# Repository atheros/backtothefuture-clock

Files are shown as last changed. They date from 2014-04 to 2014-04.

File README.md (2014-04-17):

Back To The Future Time Circuit Clock
=====================================

About
-----

This repository contains or documents and source code related to my Back To The Future Time Circuit Clock project.

All project details are hosted on hackaday.io: http://hackaday.io/project/709-Back-To-The-Future-Time-Circuit-Clock

This project is part of Hackaday Porjects Sci-Fi contest: http://hackaday.io/page/276

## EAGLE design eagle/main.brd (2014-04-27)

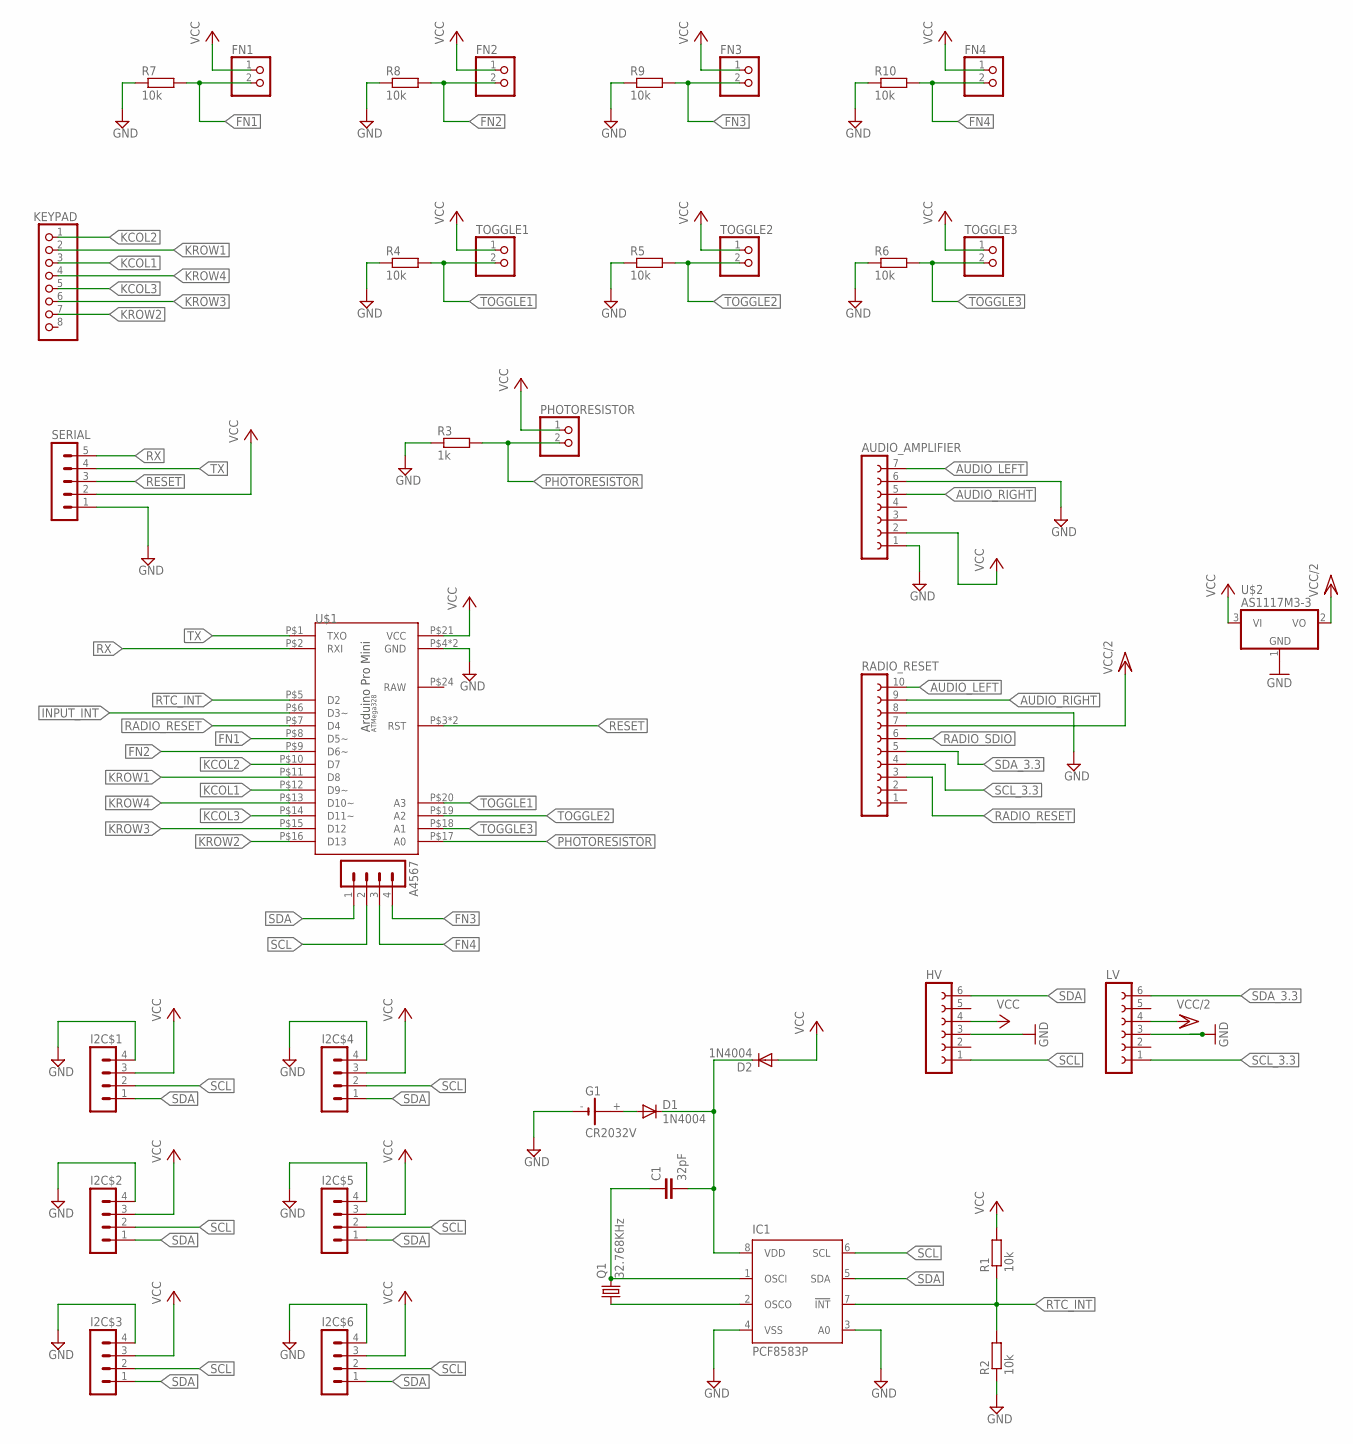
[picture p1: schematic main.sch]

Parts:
A4567: MA04-1
AUDIO_AMPLIFIER: FE07-1; FE07
C1: 32pF; C025-024X044
D1, D2: 1N4004; DO41-10
FN1, FN2, FN3, FN4: PINHD-1X2; 1X02
G1: CR2032V
HV: FE06-1; FE06
I2C$1, I2C$2, I2C$3, I2C$4, I2C$5, I2C$6: MA04-1
IC1: PCF8583P; DIL08
KEYPAD: PINHD-1X8; 1X08
LV: FE06-1; FE06
PHOTORESISTOR: PINHD-1X2; 1X02
Q1: 32.768KHz; TC26H
R1, R2, R4, R5, R6, R7, R8, R9, R10: 10k; M0805
R3: 1k; M0805
RADIO_RESET: FE10-1; FE10
SERIAL: MA05-1
TOGGLE1, TOGGLE2, TOGGLE3: PINHD-1X2; 1X02
U$1: ARDUINO-PRO-MINI-BARE; DIP24W
U$2: AS1117M3-3; SOT223

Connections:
AUDIO_LEFT: AUDIO_AMPLIFIER.7, RADIO_RESET.10
AUDIO_RIGHT: AUDIO_AMPLIFIER.5, RADIO_RESET.9
FN1: FN1.2, R7.2, U$1.P$8 (D5~)
FN2: FN2.2, R8.2, U$1.P$9 (D6~)
FN3: A4567.4, FN3.2, R9.2
FN4: A4567.3, FN4.2, R10.2
GND: AUDIO_AMPLIFIER.1, AUDIO_AMPLIFIER.6, G1.-, HV.3, I2C$1.4, I2C$2.4, I2C$3.4, I2C$4.4, I2C$5.4, I2C$6.4, IC1.3 (A0), IC1.4 (VSS), LV.3, R2.1, R3.1, R4.1, R5.1, R6.1, R7.1, R8.1, R9.1, R10.1, RADIO_RESET.8, SERIAL.1, U$1.P$4 (GND), U$1.P$23 (GND), U$2.1 (GND)
INPUT_INT: U$1.P$6 (D3~)
KCOL1: KEYPAD.3, U$1.P$12 (D9~)
KCOL2: KEYPAD.1, U$1.P$10 (D7)
KCOL3: KEYPAD.5, U$1.P$14 (D11~)
KROW1: KEYPAD.2, U$1.P$11 (D8)
KROW2: KEYPAD.7, U$1.P$16 (D13)
KROW3: KEYPAD.6, U$1.P$15 (D12)
KROW4: KEYPAD.4, U$1.P$13 (D10~)
unnamed: C1.1, IC1.1 (OSCI), Q1.2
unnamed: IC1.2 (OSCO), Q1.1
unnamed: D1.A, G1.+
unnamed: C1.2, D1.C, D2.C, IC1.8 (VDD)
PHOTORESISTOR: PHOTORESISTOR.2, R3.2, U$1.P$17 (A0)
RADIO_RESET: RADIO_RESET.3, U$1.P$7 (D4)
RADIO_SDIO: RADIO_RESET.6
RESET: SERIAL.3, U$1.P$3 (RST), U$1.P$22 (RST)
RTC_INT: IC1.7 (!INT), R1.1, R2.2, U$1.P$5 (D2)
RX: SERIAL.5, U$1.P$2 (RXI)
SCL: A4567.2, HV.1, I2C$1.2, I2C$2.2, I2C$3.2, I2C$4.2, I2C$5.2, I2C$6.2, IC1.6 (SCL)
SCL_3.3: LV.1, RADIO_RESET.4
SDA: A4567.1, HV.6, I2C$1.1, I2C$2.1, I2C$3.1, I2C$4.1, I2C$5.1, I2C$6.1, IC1.5 (SDA)
SDA_3.3: LV.6, RADIO_RESET.5
TOGGLE1: R4.2, TOGGLE1.2, U$1.P$20 (A3)
TOGGLE2: R5.2, TOGGLE2.2, U$1.P$19 (A2)
TOGGLE3: R6.2, TOGGLE3.2, U$1.P$18 (A1)
TX: SERIAL.4, U$1.P$1 (TXO)
VCC: AUDIO_AMPLIFIER.2, D2.A, FN1.1, FN2.1, FN3.1, FN4.1, HV.4, I2C$1.3, I2C$2.3, I2C$3.3, I2C$4.3, I2C$5.3, I2C$6.3, PHOTORESISTOR.1, R1.2, SERIAL.2, TOGGLE1.1, TOGGLE2.1, TOGGLE3.1, U$1.P$21 (VCC), U$2.3 (VI)
VCC/2: LV.4, RADIO_RESET.7, U$2.2 (VO)

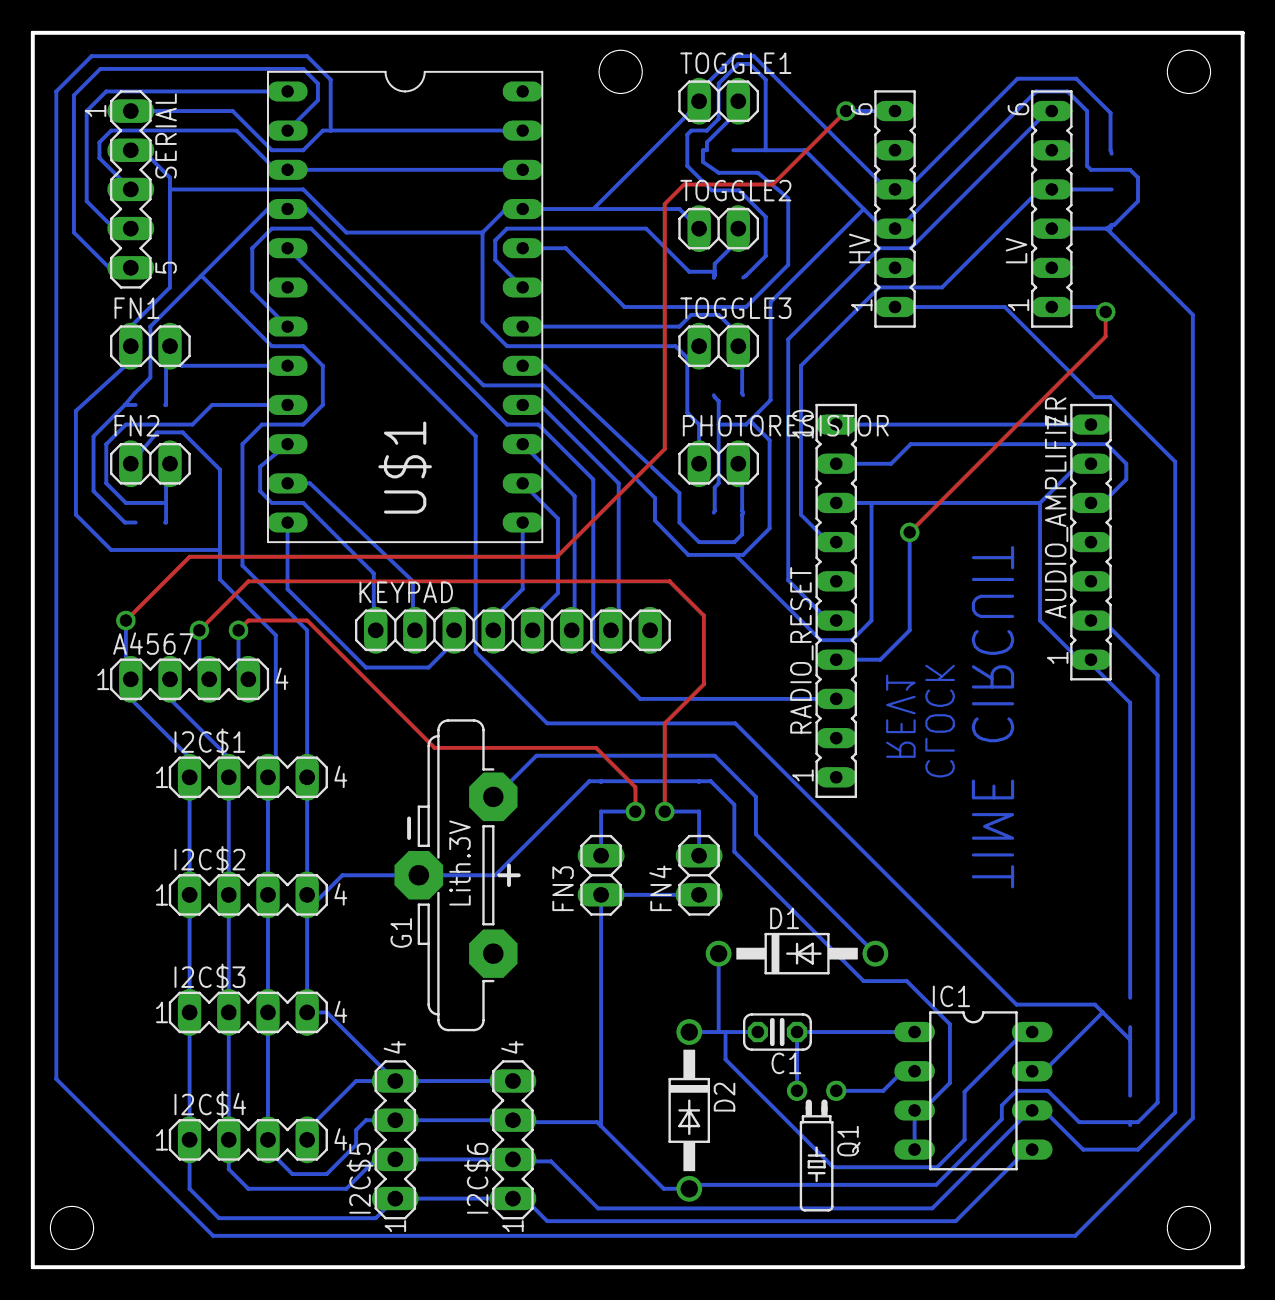
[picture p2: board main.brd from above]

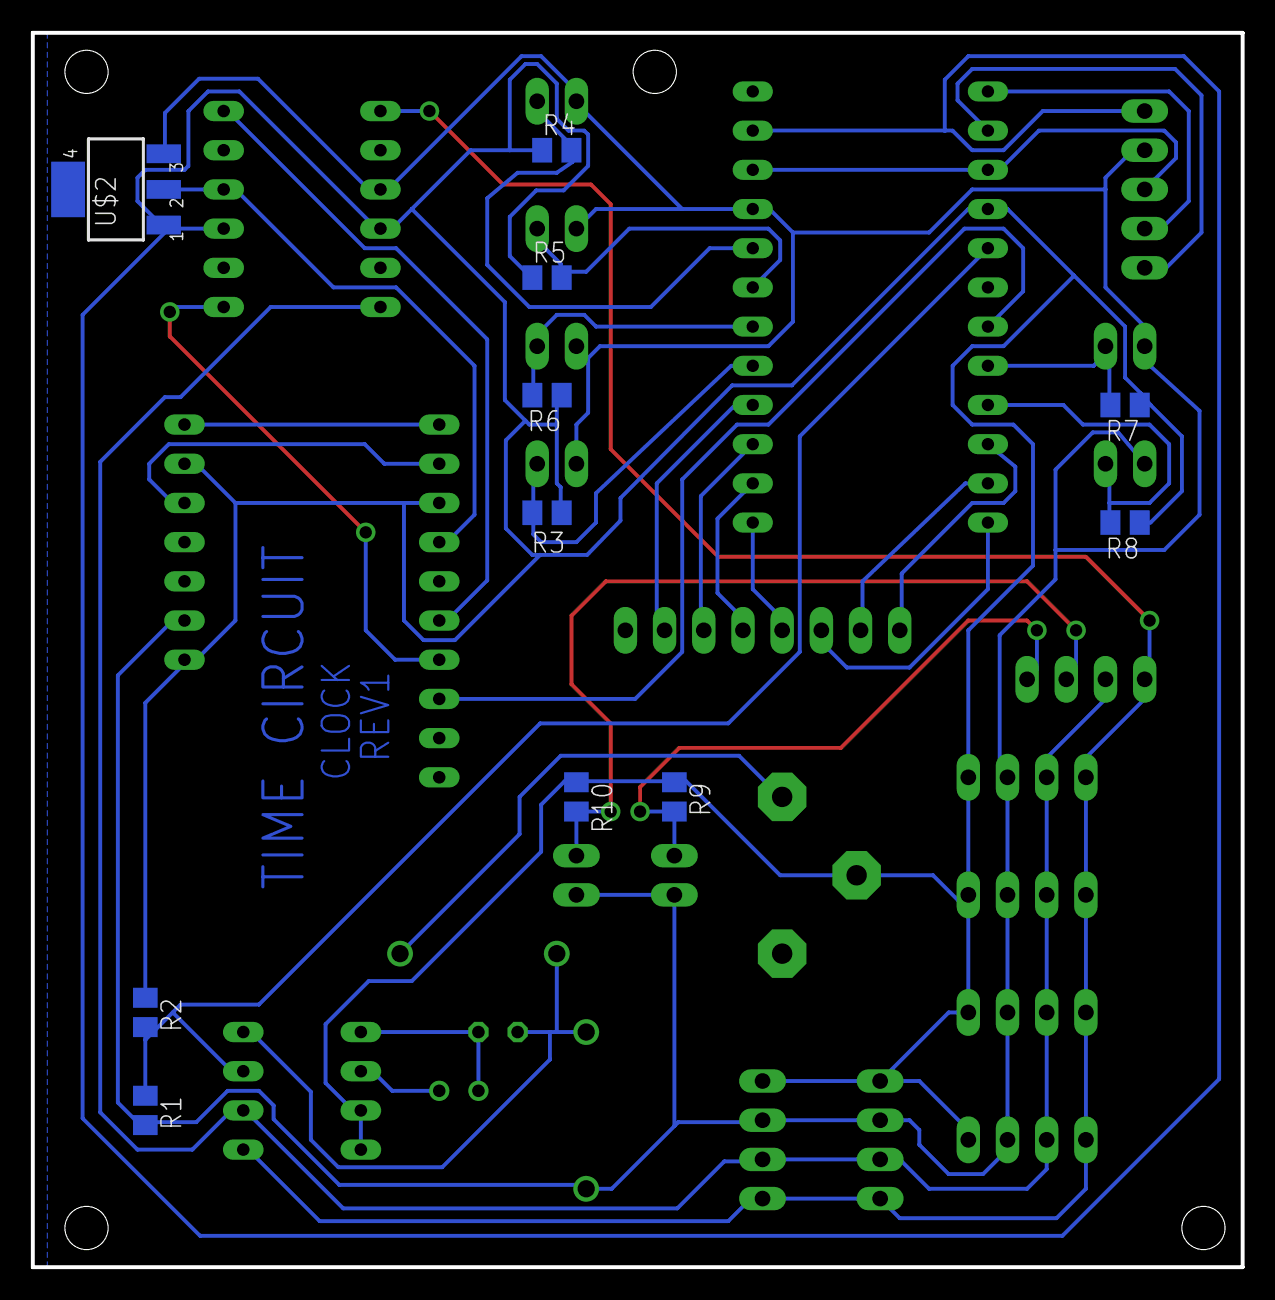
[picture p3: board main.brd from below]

Board: 2 copper layers, 78.4 x 80.0 mm, 39 parts (11 on the bottom side), 33 nets.

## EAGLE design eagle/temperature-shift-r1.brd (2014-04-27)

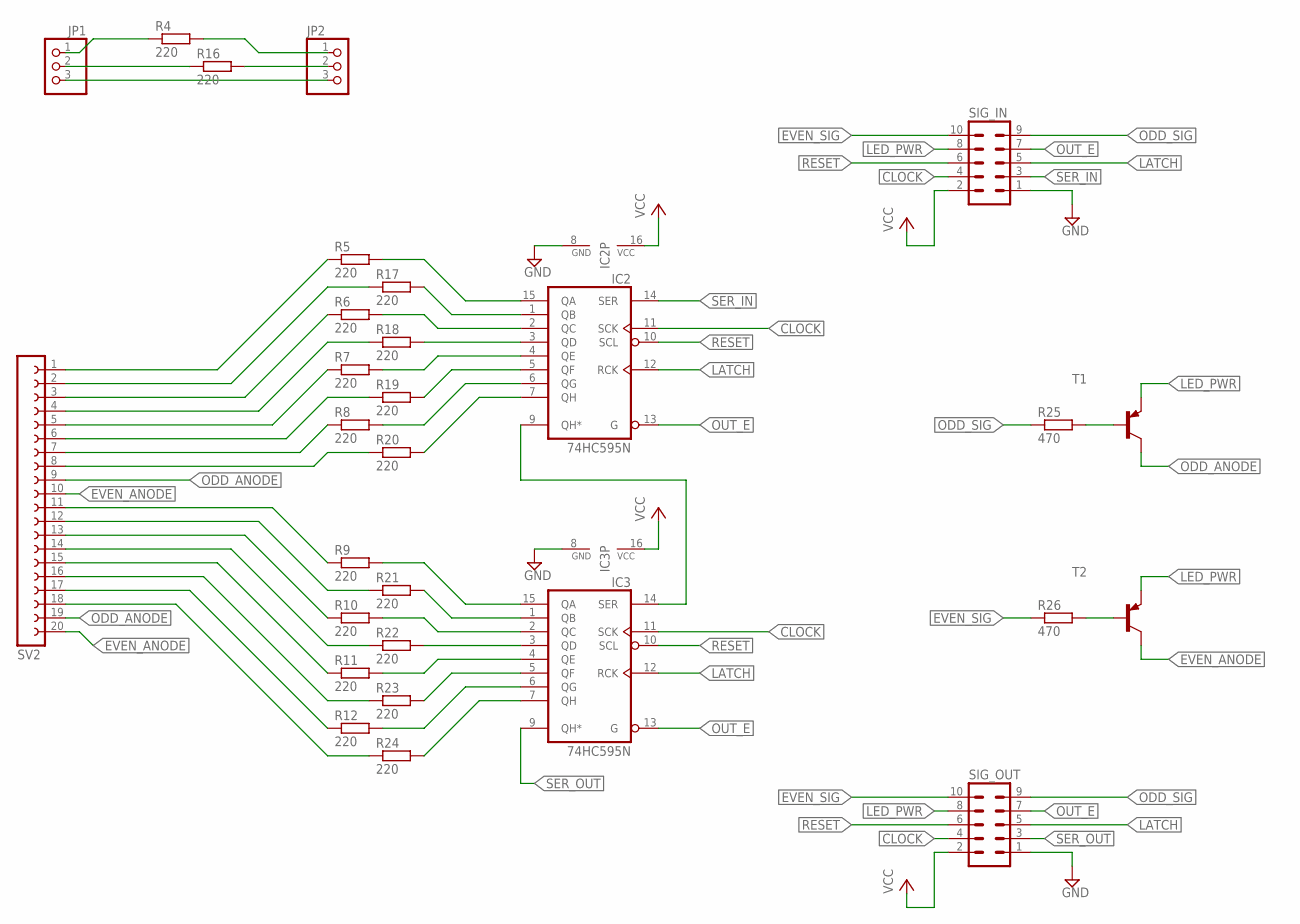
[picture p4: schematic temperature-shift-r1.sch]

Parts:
IC2, IC3: 74HC595N; DIL16
JP1, JP2: PINHD-1X3; 1X03
R4, R5, R6, R7, R8, R9, R10, R11, R12, R16, R17, R18, R19, R20, R21, R22, R23, R24: 220; R0805
R25, R26: 470; R0805
SIG_IN: MA05-2
SIG_OUT: MA05-2
SV2: FE20-1; FE20
T1, T2: BC557B-PNP-TO92-EBC; TO92-EBC

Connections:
CLOCK: IC2.11 (SCK), IC3.11 (SCK), SIG_IN.4, SIG_OUT.4
EVEN_ANODE: SV2.10, SV2.20, T2.C
EVEN_SIG: R26.1, SIG_IN.10, SIG_OUT.10
GND: IC2.8 (GND), IC3.8 (GND), SIG_IN.1, SIG_OUT.1
LATCH: IC2.12 (RCK), IC3.12 (RCK), SIG_IN.5, SIG_OUT.5
LED_PWR: SIG_IN.8, SIG_OUT.8, T1.E, T2.E
unnamed: IC2.15 (QA), R5.2
unnamed: IC2.2 (QC), R6.2
unnamed: IC2.4 (QE), R7.2
unnamed: IC2.6 (QG), R8.2
unnamed: R20.1, SV2.8
unnamed: R19.1, SV2.6
unnamed: R18.1, SV2.4
unnamed: R17.1, SV2.2
unnamed: IC2.1 (QB), R17.2
unnamed: IC2.3 (QD), R18.2
unnamed: IC2.5 (QF), R19.2
unnamed: IC2.7 (QH), R20.2
unnamed: IC3.15 (QA), R9.2
unnamed: IC3.2 (QC), R10.2
unnamed: IC3.4 (QE), R11.2
unnamed: IC3.6 (QG), R12.2
unnamed: R24.1, SV2.18
unnamed: R23.1, SV2.16
unnamed: R22.1, SV2.14
unnamed: R21.1, SV2.12
unnamed: IC3.1 (QB), R21.2
unnamed: IC3.3 (QD), R22.2
unnamed: IC3.5 (QF), R23.2
unnamed: IC3.7 (QH), R24.2
unnamed: IC2.9 (QH*), IC3.14 (SER)
unnamed: R5.1, SV2.1
unnamed: R6.1, SV2.3
unnamed: R7.1, SV2.5
unnamed: R8.1, SV2.7
unnamed: R9.1, SV2.11
unnamed: R10.1, SV2.13
unnamed: R11.1, SV2.15
unnamed: R12.1, SV2.17
unnamed: JP1.2, R16.1
unnamed: JP1.1, R4.1
unnamed: JP2.1, R4.2
unnamed: JP1.3, JP2.3
unnamed: JP2.2, R16.2
unnamed: R26.2, T2.B
unnamed: R25.2, T1.B
ODD_ANODE: SV2.9, SV2.19, T1.C
ODD_SIG: R25.1, SIG_IN.9, SIG_OUT.9
OUT_E: IC2.13 (G), IC3.13 (G), SIG_IN.7, SIG_OUT.7
RESET: IC2.10 (SCL), IC3.10 (SCL), SIG_IN.6, SIG_OUT.6
SER_IN: IC2.14 (SER), SIG_IN.3
SER_OUT: IC3.9 (QH*), SIG_OUT.3
VCC: IC2.16 (VCC), IC3.16 (VCC), SIG_IN.2, SIG_OUT.2

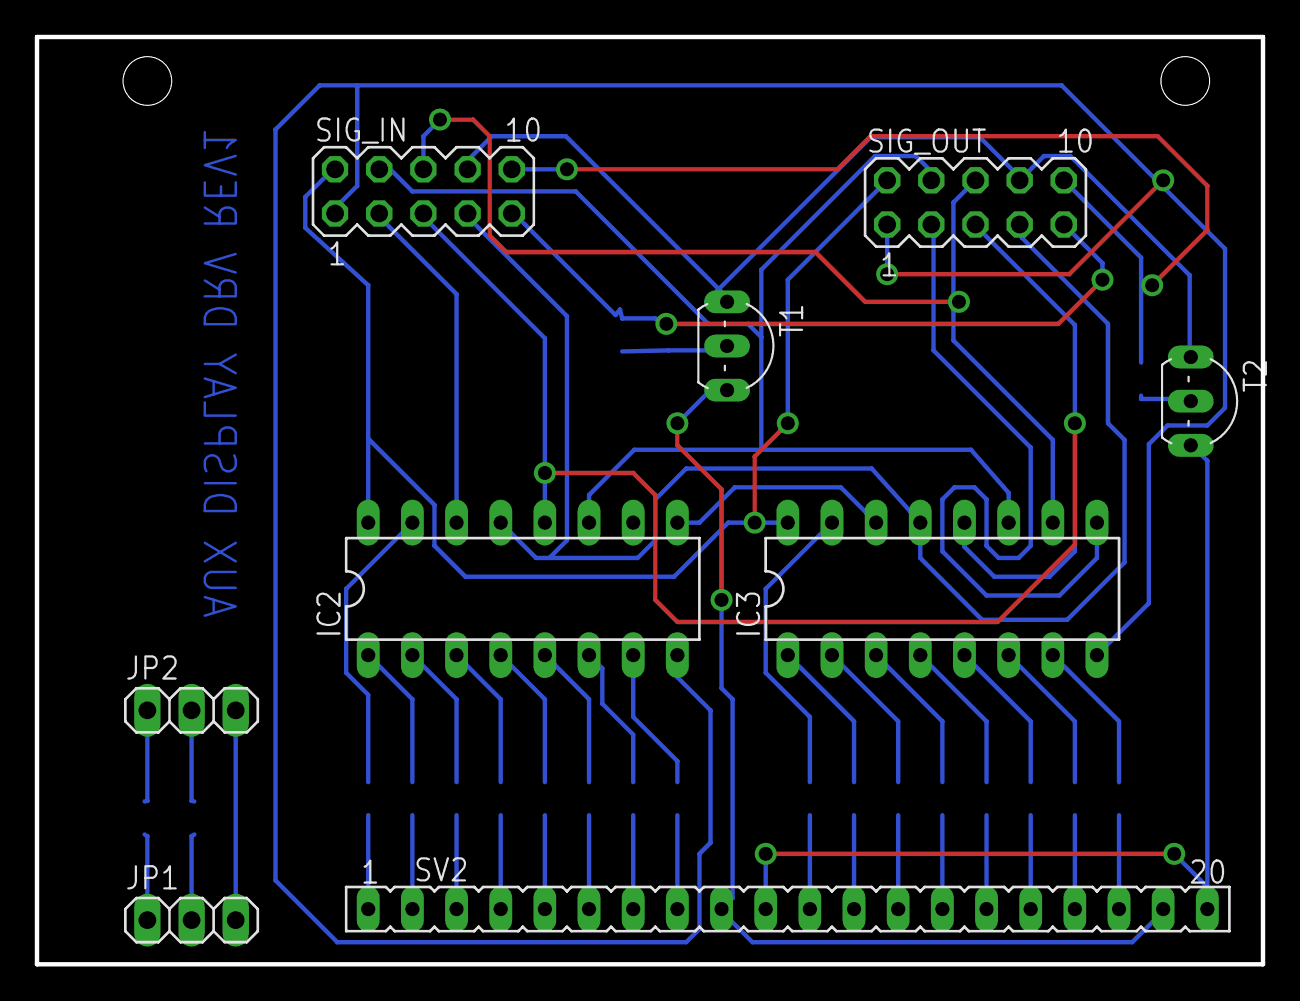
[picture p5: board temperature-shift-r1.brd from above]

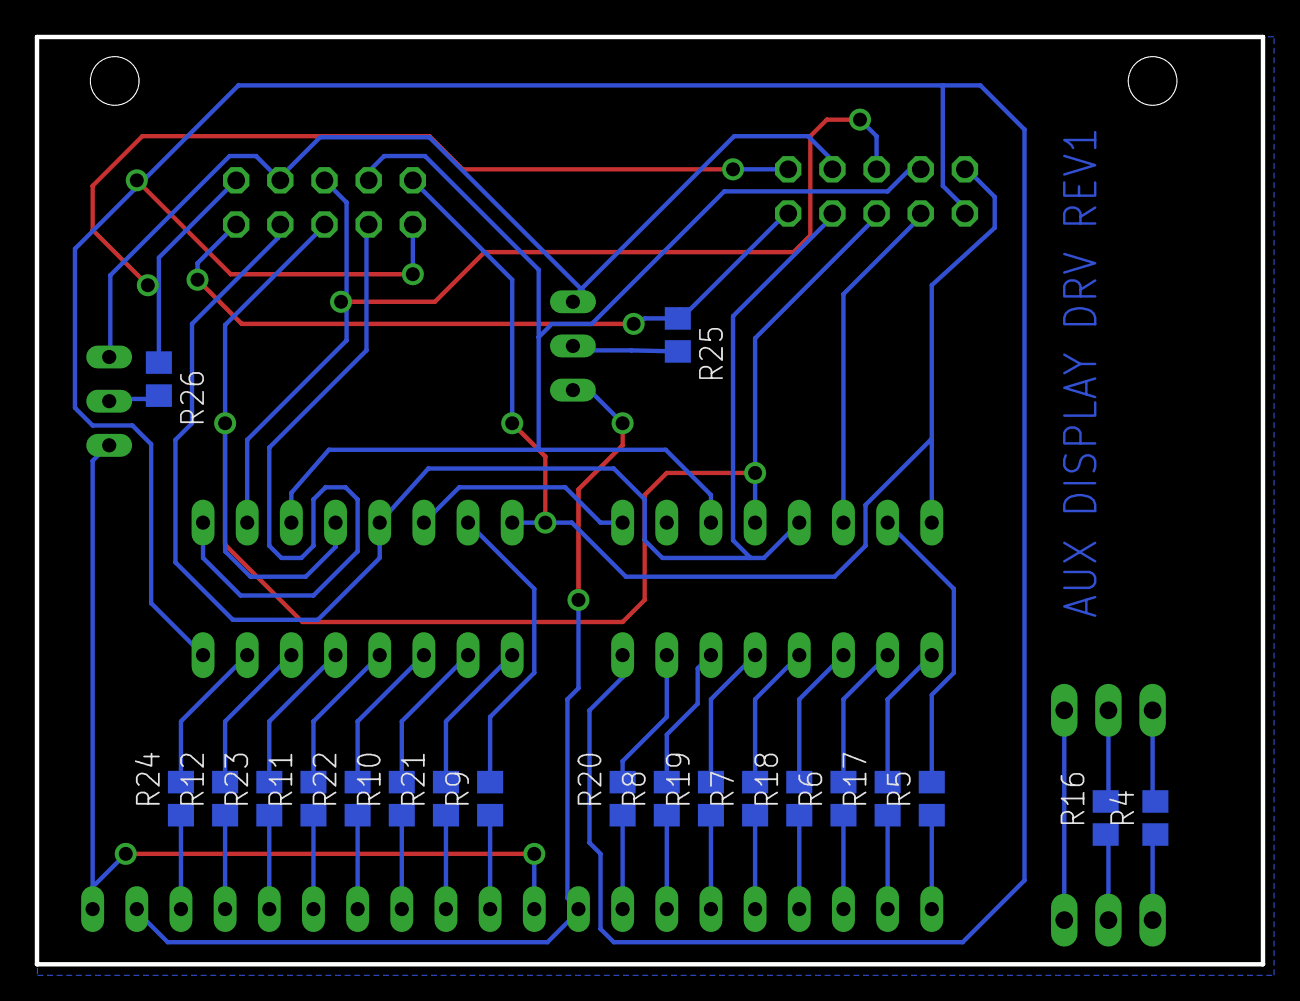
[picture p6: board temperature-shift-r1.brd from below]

Board: 2 copper layers, 70.5 x 53.3 mm, 29 parts (20 on the bottom side), 53 nets.

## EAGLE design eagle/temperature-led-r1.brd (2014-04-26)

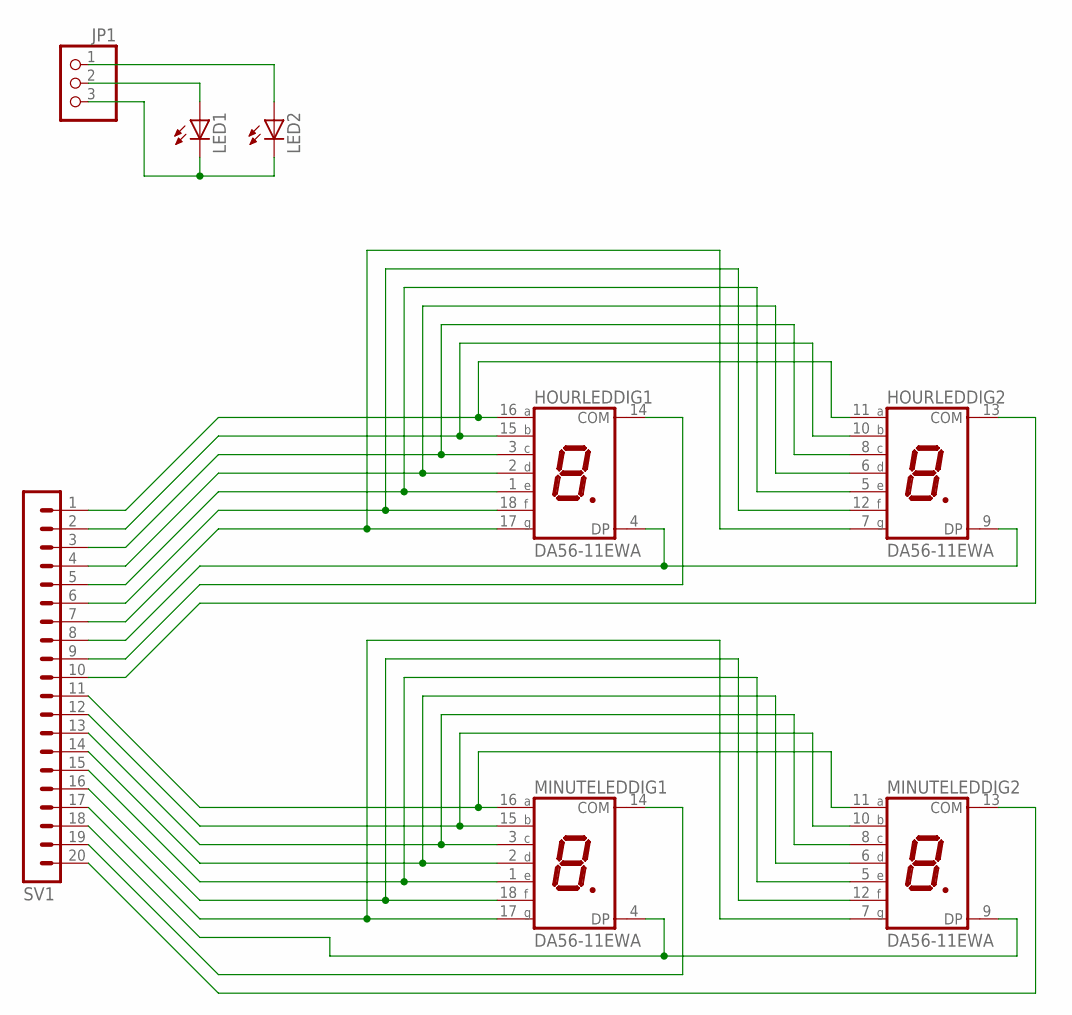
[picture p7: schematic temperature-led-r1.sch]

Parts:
HOURLED: DA56-11EWA; DA56
JP1: PINHD-1X3; 1X03
LED1, LED2: LED3MM
MINUTELED: DA56-11EWA; DA56
SV1: MA20-1W

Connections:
unnamed: HOURLED.11 (A), HOURLED.16 (A), SV1.1
unnamed: HOURLED.10 (B), HOURLED.15 (B), SV1.2
unnamed: HOURLED.3 (C), HOURLED.8 (C), SV1.3
unnamed: HOURLED.2 (D), HOURLED.6 (D), SV1.4
unnamed: HOURLED.1 (E), HOURLED.5 (E), SV1.5
unnamed: HOURLED.12 (F), HOURLED.18 (F), SV1.6
unnamed: HOURLED.7 (G), HOURLED.17 (G), SV1.7
unnamed: HOURLED.4 (DP), HOURLED.9 (DP), SV1.8
unnamed: MINUTELED.11 (A), MINUTELED.16 (A), SV1.11
unnamed: MINUTELED.10 (B), MINUTELED.15 (B), SV1.12
unnamed: MINUTELED.3 (C), MINUTELED.8 (C), SV1.13
unnamed: MINUTELED.2 (D), MINUTELED.6 (D), SV1.14
unnamed: MINUTELED.1 (E), MINUTELED.5 (E), SV1.15
unnamed: MINUTELED.12 (F), MINUTELED.18 (F), SV1.16
unnamed: MINUTELED.7 (G), MINUTELED.17 (G), SV1.17
unnamed: MINUTELED.4 (DP), MINUTELED.9 (DP), SV1.18
unnamed: HOURLED.13 (COM), SV1.10
unnamed: JP1.3, LED1.K (C), LED2.K (C)
unnamed: HOURLED.14 (COM), SV1.9
unnamed: JP1.2, LED1.A
unnamed: JP1.1, LED2.A
unnamed: MINUTELED.14 (COM), SV1.19
unnamed: MINUTELED.13 (COM), SV1.20

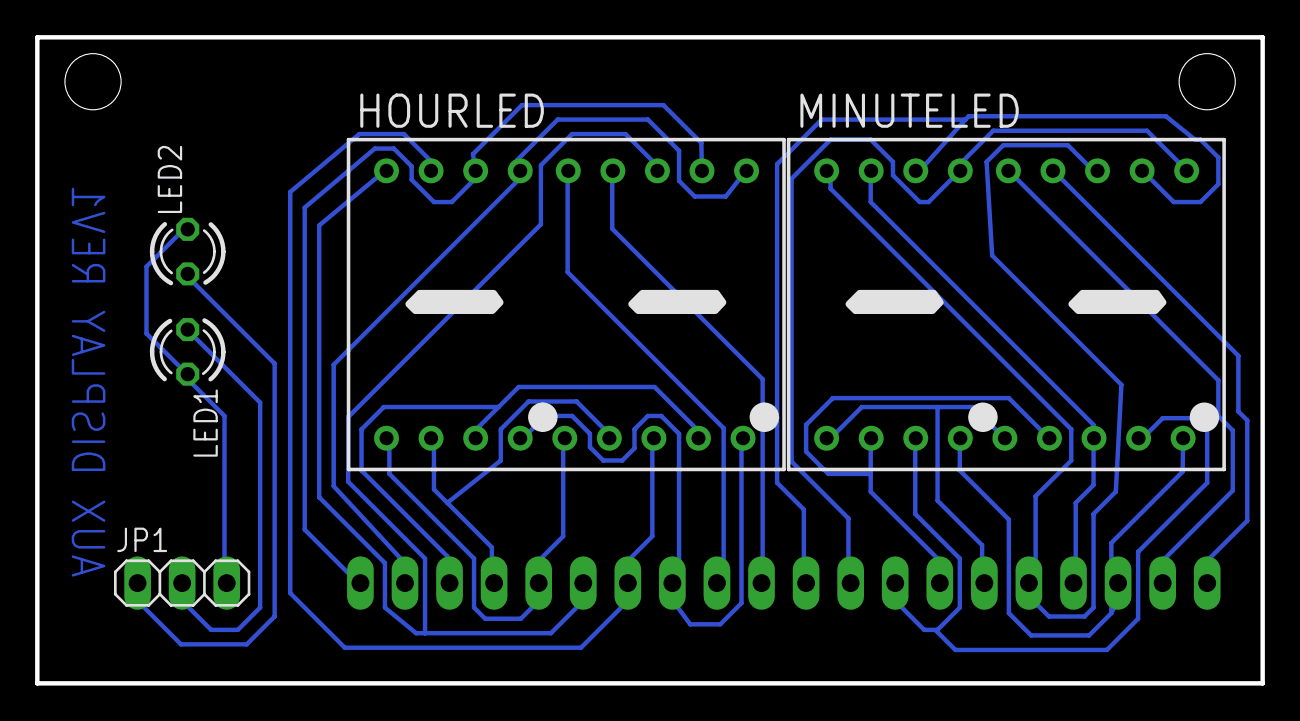
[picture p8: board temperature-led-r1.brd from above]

Board: 2 copper layers, 69.8 x 36.8 mm, 6 parts (1 on the bottom side), 23 nets.

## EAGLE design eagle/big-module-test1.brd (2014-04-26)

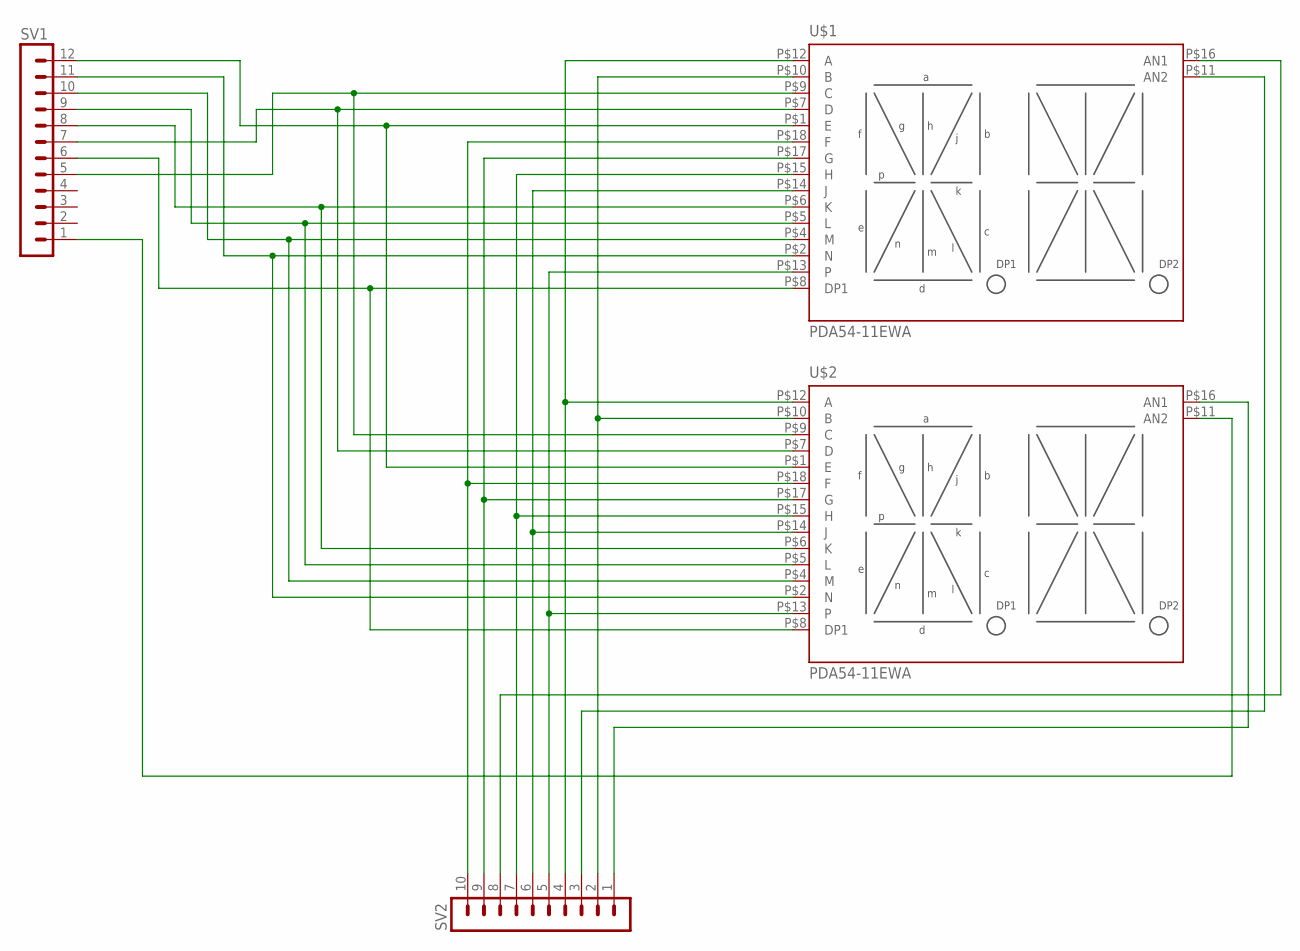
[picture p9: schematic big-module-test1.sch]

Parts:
SV1: MA12-1W
SV2: MA10-1
U$1, U$2: PDA54-11EWA; PDA54-11XX

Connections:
unnamed: SV1.12, U$1.P$1 (E), U$2.P$1 (E)
unnamed: SV1.11, U$1.P$2 (N), U$2.P$2 (N)
unnamed: SV1.10, U$1.P$4 (M), U$2.P$4 (M)
unnamed: SV1.9, U$1.P$5 (L), U$2.P$5 (L)
unnamed: SV1.8, U$1.P$6 (K), U$2.P$6 (K)
unnamed: SV1.7, U$1.P$7 (D), U$2.P$7 (D)
unnamed: SV1.6, U$1.P$8 (DP1), U$2.P$8 (DP1)
unnamed: SV1.5, U$1.P$9 (C), U$2.P$9 (C)
unnamed: SV2.10, U$1.P$18 (F), U$2.P$18 (F)
unnamed: SV2.9, U$1.P$17 (G), U$2.P$17 (G)
unnamed: SV2.8, U$1.P$16 (AN1)
unnamed: SV2.7, U$1.P$15 (H), U$2.P$15 (H)
unnamed: SV2.6, U$1.P$14 (J), U$2.P$14 (J)
unnamed: SV2.5, U$1.P$13, U$2.P$13
unnamed: SV2.4, U$1.P$12 (A), U$2.P$12 (A)
unnamed: SV2.3, U$1.P$11 (AN2)
unnamed: SV2.2, U$1.P$10 (B), U$2.P$10 (B)
unnamed: SV2.1, U$2.P$16 (AN1)
unnamed: SV1.1, U$2.P$11 (AN2)

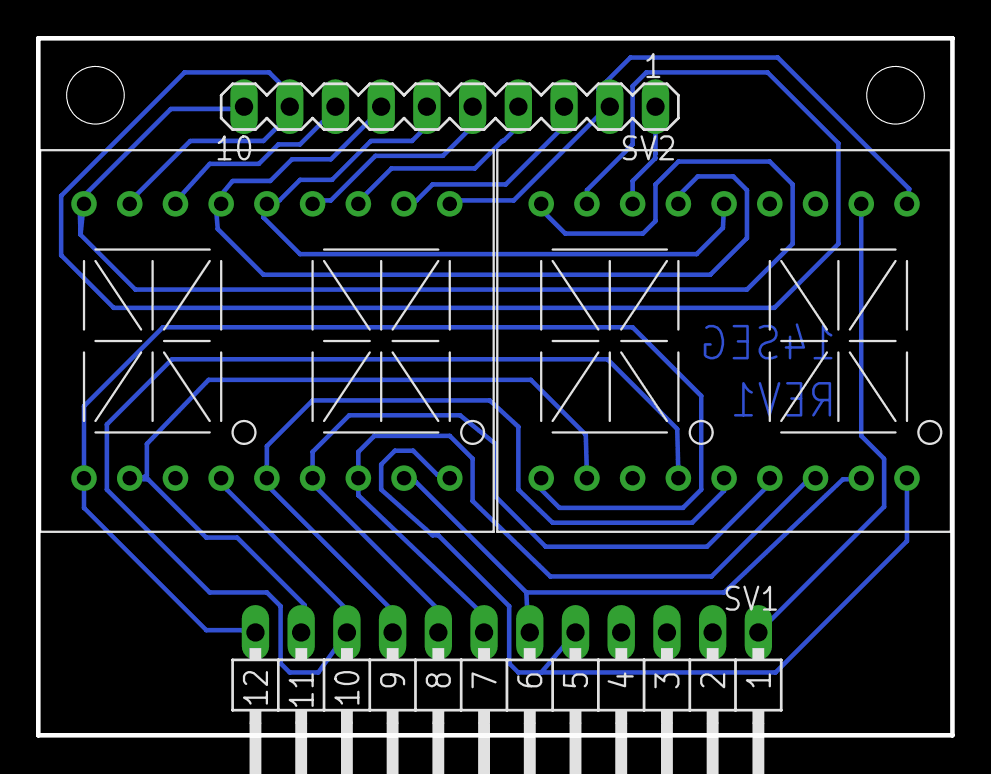
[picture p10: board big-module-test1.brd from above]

Board: 2 copper layers, 50.8 x 38.7 mm, 4 parts (0 on the bottom side), 19 nets.

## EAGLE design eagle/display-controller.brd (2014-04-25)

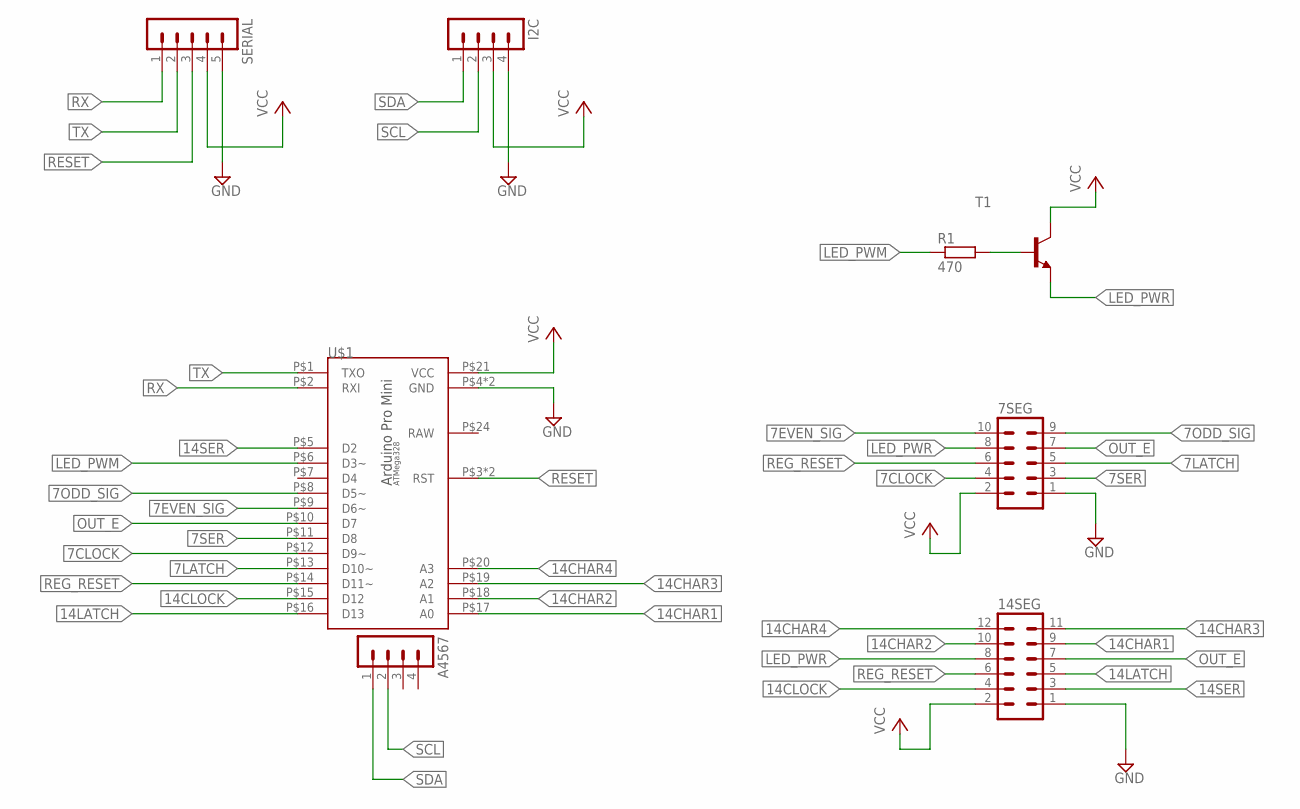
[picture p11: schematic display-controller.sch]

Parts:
7SEG: MA05-2
14SEG: MA06-2
A4567: MA04-1
I2C: MA04-1
R1: 470; 0207/2V
SERIAL: MA05-1
T1: BC337-40-NPN-TO92-CBE; TO92-CBE
U$1: ARDUINO-PRO-MINI-BARE; DIP24W

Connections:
7CLOCK: 7SEG.4, U$1.P$12 (D9~)
7EVEN_SIG: 7SEG.10, U$1.P$9 (D6~)
7LATCH: 7SEG.5, U$1.P$13 (D10~)
7ODD_SIG: 7SEG.9, U$1.P$8 (D5~)
7SER: 7SEG.3, U$1.P$11 (D8)
14CHAR1: 14SEG.9, U$1.P$17 (A0)
14CHAR2: 14SEG.10, U$1.P$18 (A1)
14CHAR3: 14SEG.11, U$1.P$19 (A2)
14CHAR4: 14SEG.12, U$1.P$20 (A3)
14CLOCK: 14SEG.4, U$1.P$15 (D12)
14LATCH: 14SEG.5, U$1.P$16 (D13)
14SER: 14SEG.3, U$1.P$5 (D2)
GND: 7SEG.1, 14SEG.1, I2C.4, SERIAL.5, U$1.P$4 (GND), U$1.P$23 (GND)
LED_PWM: R1.1, U$1.P$6 (D3~)
LED_PWR: 7SEG.8, 14SEG.8, T1.E
unnamed: R1.2, T1.B
OUT_E: 7SEG.7, 14SEG.7, U$1.P$10 (D7)
REG_RESET: 7SEG.6, 14SEG.6, U$1.P$14 (D11~)
RESET: SERIAL.3, U$1.P$3 (RST), U$1.P$22 (RST)
RX: SERIAL.1, U$1.P$2 (RXI)
SCL: A4567.2, I2C.2
SDA: A4567.1, I2C.1
TX: SERIAL.2, U$1.P$1 (TXO)
VCC: 7SEG.2, 14SEG.2, I2C.3, SERIAL.4, T1.C, U$1.P$21 (VCC)

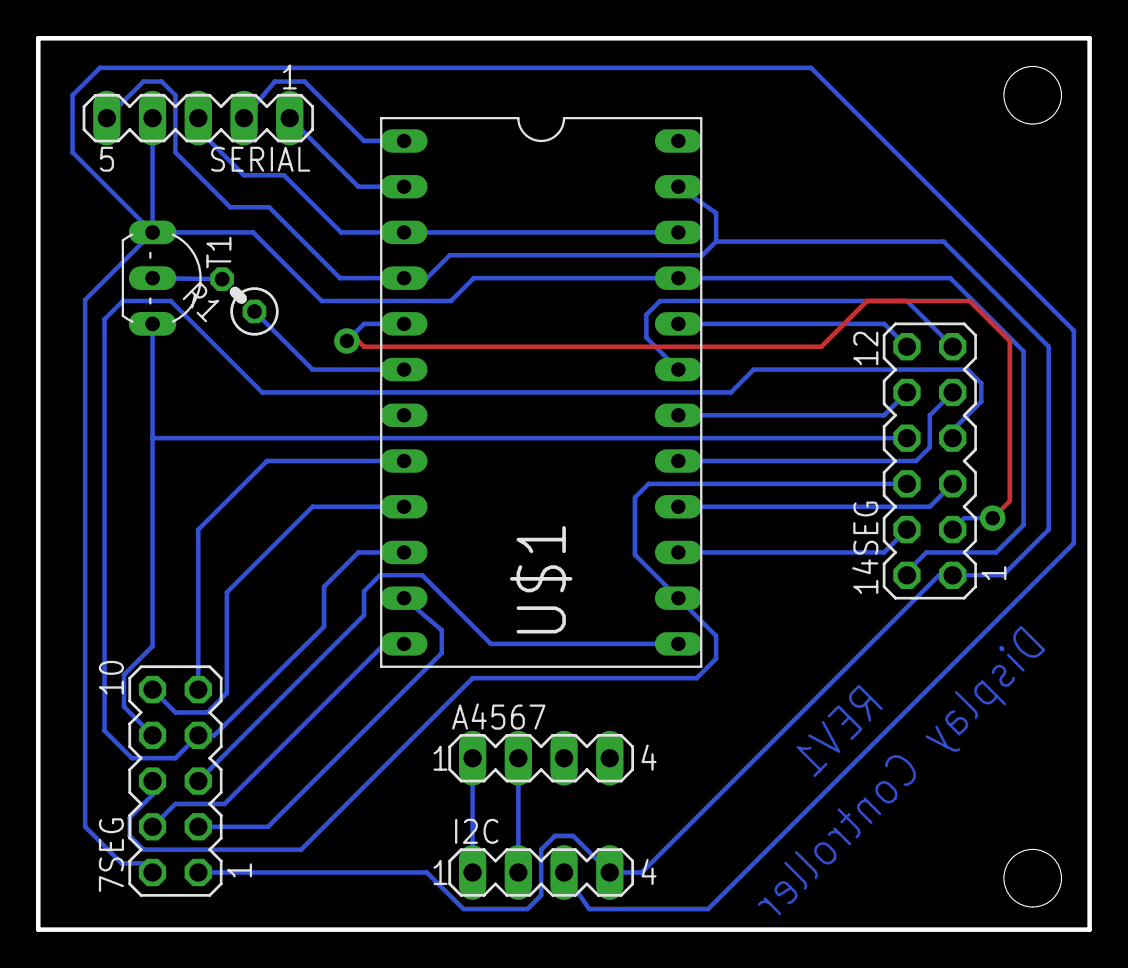
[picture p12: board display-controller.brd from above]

Board: 2 copper layers, 58.4 x 49.5 mm, 8 parts (0 on the bottom side), 24 nets.

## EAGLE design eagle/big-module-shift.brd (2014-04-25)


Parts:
IC1, IC2: 74HC595N; DIL16
R1, R2, R3, R4, R5, R6, R7, R8, R9, R10, R11, R12, R13, R14, R15: 220; M0805
R16, R17, R18, R25: 470; R0805
SIG_IN: MA06-2
SIG_OUT: MA06-2
SV1: MA12-1
SV2: MA10-1
T1, T2, T3, T4: BC557B-PNP-TO92-EBC; TO92-EBC

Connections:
ANODE1: SV2.8, T1.C
ANODE2: SV2.3, T2.C
ANODE3: SV2.1, T3.C
ANODE4: SV1.1, T4.C
CHAR1: R25.1, SIG_IN.9, SIG_OUT.9
CHAR2: R16.1, SIG_IN.10, SIG_OUT.10
CHAR3: R17.1, SIG_IN.11, SIG_OUT.11
CHAR4: R18.1, SIG_IN.12, SIG_OUT.12
CLOCK: IC1.11 (SCK), IC2.11 (SCK), SIG_IN.4, SIG_OUT.4
GND: IC1.8 (GND), IC2.8 (GND), SIG_IN.1, SIG_OUT.1
LATCH: IC1.12 (RCK), IC2.12 (RCK), SIG_IN.5, SIG_OUT.5
LED_PWR: SIG_IN.8, SIG_OUT.8, T1.E, T2.E, T3.E, T4.E
unnamed: IC1.15 (QA), R1.2
unnamed: IC1.1 (QB), R2.2
unnamed: IC1.2 (QC), R3.2
unnamed: IC1.3 (QD), R4.2
unnamed: IC1.4 (QE), R5.2
unnamed: IC1.5 (QF), R6.2
unnamed: IC1.6 (QG), R7.2
unnamed: IC1.7 (QH), R8.2
unnamed: R1.1, SV1.12
unnamed: R2.1, SV1.11
unnamed: R3.1, SV1.10
unnamed: R4.1, SV1.9
unnamed: R5.1, SV1.8
unnamed: R6.1, SV1.7
unnamed: R7.1, SV1.6
unnamed: R8.1, SV1.5
unnamed: IC1.9 (QH*), IC2.14 (SER)
unnamed: IC2.15 (QA), R9.2
unnamed: IC2.1 (QB), R10.2
unnamed: IC2.2 (QC), R11.2
unnamed: IC2.3 (QD), R12.2
unnamed: IC2.4 (QE), R13.2
unnamed: IC2.5 (QF), R14.2
unnamed: IC2.6 (QG), R15.2
unnamed: R9.1, SV2.10
unnamed: R10.1, SV2.9
unnamed: R11.1, SV2.7
unnamed: R12.1, SV2.6
unnamed: R13.1, SV2.5
unnamed: R14.1, SV2.4
unnamed: R15.1, SV2.2
unnamed: R16.2, T2.B
unnamed: R17.2, T3.B
unnamed: R18.2, T4.B
unnamed: R25.2, T1.B
OUT_E: IC1.13 (G), IC2.13 (G), SIG_IN.7, SIG_OUT.7
RESET: IC1.10 (SCL), IC2.10 (SCL), SIG_IN.6, SIG_OUT.6
SER_IN: IC1.14 (SER), SIG_IN.3
SER_OUT: IC2.9 (QH*), SIG_OUT.3
VCC: IC1.16 (VCC), IC2.16 (VCC), SIG_IN.2, SIG_OUT.2

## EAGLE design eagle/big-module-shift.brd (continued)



Board: 2 copper layers, 50.8 x 64.8 mm, 29 parts (19 on the bottom side), 52 nets.

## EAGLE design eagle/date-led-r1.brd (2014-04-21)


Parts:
LED1, LED2, LED3: DA56-11EWA; DA56
SV1: MA20-1W
SV2: MA10-1W

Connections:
unnamed: LED1.11 (A), LED1.16 (A), SV1.1
unnamed: LED1.10 (B), LED1.15 (B), SV1.2
unnamed: LED1.3 (C), LED1.8 (C), SV1.3
unnamed: LED1.2 (D), LED1.6 (D), SV1.4
unnamed: LED1.1 (E), LED1.5 (E), SV1.5
unnamed: LED1.12 (F), LED1.18 (F), SV1.6
unnamed: LED1.7 (G), LED1.17 (G), SV1.7
unnamed: LED1.4 (DP), LED1.9 (DP), SV1.8
unnamed: LED2.11 (A), LED2.16 (A), SV1.11
unnamed: LED2.10 (B), LED2.15 (B), SV1.12
unnamed: LED2.3 (C), LED2.8 (C), SV1.13
unnamed: LED2.2 (D), LED2.6 (D), SV1.14
unnamed: LED2.1 (E), LED2.5 (E), SV1.15
unnamed: LED2.12 (F), LED2.18 (F), SV1.16
unnamed: LED2.7 (G), LED2.17 (G), SV1.17
unnamed: LED2.4 (DP), LED2.9 (DP), SV1.18
unnamed: LED1.13 (COM), SV1.10
unnamed: LED3.11 (A), LED3.16 (A), SV2.1
unnamed: LED1.14 (COM), SV1.9
unnamed: LED3.10 (B), LED3.15 (B), SV2.2
unnamed: LED3.3 (C), LED3.8 (C), SV2.3
unnamed: LED3.2 (D), LED3.6 (D), SV2.4
unnamed: LED3.1 (E), LED3.5 (E), SV2.5
unnamed: LED3.12 (F), LED3.18 (F), SV2.6
unnamed: LED2.14 (COM), SV1.19
unnamed: LED2.13 (COM), SV1.20
unnamed: LED3.7 (G), LED3.17 (G), SV2.7
unnamed: LED3.4 (DP), LED3.9 (DP), SV2.8
unnamed: LED3.14 (COM), SV2.9
unnamed: LED3.13 (COM), SV2.10



Board: 2 copper layers, 91.1 x 36.8 mm, 5 parts (2 on the bottom side), 30 nets.

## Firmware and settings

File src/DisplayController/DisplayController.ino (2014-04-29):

#include <SerialDisplay7.h>
#include <SerialDisplay14.h>

#include <Wire.h>

#define I2C_ADDRESS  0x04


#define PIN_DATA7   8
#define PIN_CLOCK7  9
#define PIN_LATCH7  10
// signal to turn odd characters on
#define PIN_CH7_ODD  5
// signal to turn even characters on
#define PIN_CH7_EVEN 6
// signal to enable display output


#define PIN_DATA14    2
#define PIN_CLOCK14   12
#define PIN_LATCH14   13
// signal to turn characters on
#define PIN_CH14_1  14
#define PIN_CH14_2  15
#define PIN_CH14_3  16
#define PIN_CH14_4  17


// common pins
#define PIN_PWM       3
#define PIN_OUTPUT_E  7
#define PIN_RESET     11


// number of 7-segment displays
#define SEG7_SIZE  24
// 7-segment display object
SerialDisplay7 display7(SEG7_SIZE, PIN_DATA7, PIN_CLOCK7, PIN_LATCH7, PIN_CH7_ODD, PIN_CH7_EVEN, 1);
// character buffer for 7-segment display


// number of 14-segment displays
#define SEG14_SIZE  20
// 14-segment display object
SerialDisplay14 display14(SEG14_SIZE, PIN_DATA14, PIN_CLOCK14, PIN_LATCH14, PIN_CH14_1, PIN_CH14_2, PIN_CH14_3, PIN_CH14_4);
// character buffer



void setPwmFrequency(int pin, int divisor) {
  byte mode;
  if(pin == 5 || pin == 6 || pin == 9 || pin == 10) {
    switch(divisor) {
      case 1: mode = 0x01; break;
      case 8: mode = 0x02; break;
      case 64: mode = 0x03; break;
      case 256: mode = 0x04; break;
      case 1024: mode = 0x05; break;
      default: return;
    }
    if(pin == 5 || pin == 6) {
      TCCR0B = TCCR0B & 0b11111000 | mode;
    } else {
      TCCR1B = TCCR1B & 0b11111000 | mode;
    }
  } else if(pin == 3 || pin == 11) {
    switch(divisor) {
      case 1: mode = 0x01; break;
      case 8: mode = 0x02; break;
      case 32: mode = 0x03; break;
      case 64: mode = 0x04; break;
      case 128: mode = 0x05; break;
      case 256: mode = 0x06; break;
      case 1024: mode = 0x7; break;
      default: return;
    }
    TCCR2B = TCCR2B & 0b11111000 | mode;
  }
}

void delay2(long int ms) {
  long int dest = millis() + ms;
  volatile int i;
  while(millis() < dest) {
    i++;
  }
}


#define DEBUG
#ifdef DEBUG
#define  DPRINT(text) Serial.println(text)
#else
#define  DPRINT(text)
#endif



enum {
  I2C_CMD_SET7  = 1,
  I2C_CMD_SET14 = 2,
  I2C_CMD_RESETA = 3,
  I2C_CMD_BLINK7 = 4,
  I2C_CMD_BLINK14 = 5
};


#define I2C_BUFFER_SIZE  60
int i2c_cmd = 0;
int i2c_expected_size = -1;
int i2c_size = 0;
char i2c_buffer[I2C_BUFFER_SIZE];

void i2c_receive(int count) {
  byte c, i;
  DPRINT("i2c receive bytes:");
  DPRINT(count);
  
  while (Wire.available()) {
    c = Wire.read();
    // try twice
    for (i = 0; i < 2; i++) {
      if (i2c_cmd == 0) {
        // accept new command
        if (c == I2C_CMD_RESETA) {
          display7.resetAttributes();
          display14.resetAttributes();
        } else if (c == I2C_CMD_SET7 || c == I2C_CMD_SET14 || c == I2C_CMD_BLINK7 || c == I2C_CMD_BLINK14) {
          // set display
          i2c_cmd = c;
          i2c_expected_size = -1;
          i2c_size = 0;
          break;
        } else {
          // reset I2C
          i2c_cmd = 0;
        }
      } else if ((i2c_cmd == I2C_CMD_SET7 || i2c_cmd == I2C_CMD_SET14 || i2c_cmd == I2C_CMD_BLINK7 || i2c_cmd == I2C_CMD_BLINK14) && i2c_expected_size == -1) {
        // get size of input for text commands
        i2c_expected_size = c;
        if (c == 0 && (i2c_cmd == I2C_CMD_SET7 || i2c_cmd == I2C_CMD_SET14)) {
          // no text to display - can be used to clear the screen
          if (i2c_cmd == I2C_CMD_SET7) {
            display7.write("", 0);
          } else if (i2c_cmd == I2C_CMD_SET14) {
            display14.write("", 0);
          }
          i2c_cmd = 0;
        }
        break;
      } else if ((i2c_cmd == I2C_CMD_SET7 || i2c_cmd == I2C_CMD_SET14) && i2c_expected_size != -1) {
        // get input for text commands
        if (i2c_size > I2C_BUFFER_SIZE) {
          // prevent buffer overflow and ignore the rest of input
          i2c_size++;
        } else {
          // add to buffer
          i2c_buffer[i2c_size++] = c;
        }
        
        if (i2c_size == i2c_expected_size) {
          // we got the data we were waiting for
          
          if (i2c_size > I2C_BUFFER_SIZE) {
            // if there was a buffer overflow, replace the size to prevent problems
            i2c_size = I2C_BUFFER_SIZE;
          }
          
          // execute the command
          if (i2c_cmd == I2C_CMD_SET7) {
            display7.write(i2c_buffer, i2c_size);
          } else if (i2c_cmd == I2C_CMD_SET14) {
            display14.write(i2c_buffer, i2c_size);
          }
          i2c_cmd = 0;
        }
        break;
      } else if ((i2c_cmd == I2C_CMD_BLINK7 || i2c_cmd == I2C_CMD_BLINK14) && i2c_expected_size != -1) {
        if (i2c_cmd == I2C_CMD_BLINK7) {
          DPRINT("I2C_CMD_BLINK7");
          display7.blink(i2c_expected_size, c);
        } else if (i2c_cmd == I2C_CMD_BLINK14) {
          DPRINT("I2C_CMD_BLINK14");
          display14.blink(i2c_expected_size, c); 
        }
        DPRINT(i2c_expected_size);
        DPRINT(c);
        i2c_cmd = 0;
      } else {
        // unknown input
      }
    }
  }
}



void setup() {
#ifdef DEBUG
  Serial.begin(115200);
#endif
  // initialize pins we will be using
  pinMode(PIN_DATA7, OUTPUT);
  pinMode(PIN_CLOCK7, OUTPUT);
  pinMode(PIN_LATCH7, OUTPUT);
  pinMode(PIN_CH7_ODD, OUTPUT);
  pinMode(PIN_CH7_EVEN, OUTPUT);
  
  pinMode(PIN_DATA14, OUTPUT);
  pinMode(PIN_CLOCK14, OUTPUT);
  pinMode(PIN_LATCH14, OUTPUT);
  pinMode(PIN_CH14_1, OUTPUT);
  pinMode(PIN_CH14_2, OUTPUT);
  pinMode(PIN_CH14_3, OUTPUT);
  pinMode(PIN_CH14_4, OUTPUT);

  
  pinMode(PIN_RESET, OUTPUT);
  pinMode(PIN_OUTPUT_E, OUTPUT);
  pinMode(PIN_PWM, OUTPUT);

  // reset all 74hc595
  digitalWrite(PIN_RESET, LOW);
  digitalWrite(PIN_RESET, HIGH);
  
  // enable output
  digitalWrite(PIN_OUTPUT_E, LOW);
  
  // set brightness to medium at the start
  setPwmFrequency(PIN_PWM, 1);
  analogWrite(PIN_PWM, 10); 
  
  // test string
  //display7.write("261985012405195506000000", SEG7_SIZE);
  //display7.write  ("101214161820212325272930", SEG7_SIZE);
  //display14.write("OCT NOV HACKADAY.IO", 19);
  //display14.write("ABCDEFGHIJKLMNOPQRST", SEG14_SIZE);
  
      Wire.begin(I2C_ADDRESS);
      Wire.onReceive(i2c_receive);
      DPRINT("Wire initialized");

}


bool initDone = false;


void initFunc() {
  static int initPhase = 0;
  static int initCounter = 0;
  
  if (initPhase == 0) {
    display7.write("888888888888888888888888", SEG7_SIZE);
    display14.write("\0\0\0\0\0\0\0\0\0\0\0\0\0\0\0\0\0\0\0\0", SEG14_SIZE);
    
    analogWrite(PIN_PWM, 255);    
    initPhase = 1; 
  } else if (initPhase == 1) {
    if (initCounter == 50) {
      analogWrite(PIN_PWM, 40);
    } else if (initCounter == 100) {
      analogWrite(PIN_PWM, 80);
    } else if (initCounter == 200) {
      analogWrite(PIN_PWM, 120);
    } else if (initCounter == 300) {
      analogWrite(PIN_PWM, 150);
    } else if (initCounter == 400) {
      analogWrite(PIN_PWM, 200);
      initDone = true;
      // default text
      display7.write("261985012405195506000000", SEG7_SIZE);
      display14.write("OCT NOV /HACKADAY.IO/", 21);
      
    }
    
    display7.update();
    display14.update();
    initCounter++;
    delay(1);
  }
}


int counter = 0;

void loop() {
  if (!initDone) {
    initFunc();
    return;
  }

  
// test hide attribute
//  if (counter == 0) {
//    display7.resetAttributes();
//    display7.hide(chr, 2);
//    chr++;
//    if (chr > SEG7_SIZE) {
//     chr = 0;
//    }   
//  }
// test hide group of displays
/*
  if (counter == 0 && 0) {
    if (chr == 0) {
      // show all
      display7.resetAttributes();
    } else if (chr == 1) {
      // hide first
      display7.resetAttributes();
      display7.hide(0, 10);
    } else if (chr == 2) {
      // hide second, show firs
      display7.resetAttributes();
      display7.hide(10, 10);
    } else if (chr == 3) {
      // hide all
      display7.resetAttributes();
      display7.hide(0, 20);
    }
    
    chr++;
    if (chr == 4) {
      chr = 0;
    }
  }
  
  // update the display
  display7.update();
  display14.update();
  // and wait a bit
  
  
  counter++;
  if (counter == 100) {
    counter = 0;
    chr+=5;
    if (chr > 255) {
      chr = 0;
    }
    analogWrite(PIN_PWM, chr); 
  }
*/

  if (counter == 1000) {
    display7.updateBlink(true);
    display14.updateBlink(true);
  } else if (counter == 2000) {
    display7.updateBlink(false);
    display14.updateBlink(false);
    counter = 0;
  }    
  display7.update();
  display14.update();
  delay(1);
  counter++;
}

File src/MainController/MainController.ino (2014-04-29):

#include <Bounce2.h>

#include <Si4703_Breakout.h>

#include <Keypad.h>

#include <PCF8583.h>

#include <Wire.h>

#define FIRMWARE_VERSION "0.0.1"

// I2C address of display controller
#define DISPLAY_ADDRESS 0x04
#define RTC_ADDRESS  0xA0

#define I2C_SDA A4
#define I2C_SCL A5
#define RADIO_RESET_PIN 4


int radioVolume = 4;
int radioChannel = 1075;
Si4703_Breakout radio(RADIO_RESET_PIN, I2C_SDA, I2C_SCL);

#define BUTTON_FN1  5
#define BUTTON_FN2  6
#define BUTTON_FN3  A6 /*A6*/
#define BUTTON_FN4  A7 /*A7*/
Bounce buttonFn1 = Bounce();
Bounce buttonFn2 = Bounce();



const byte keypadRows = 4; //four rows
const byte keypadCols = 3; //three columns
char keypadKeys[keypadRows][keypadCols] = {
  {'1','2','3'},
  {'4','5','6'},
  {'7','8','9'},
  {'*','0','#'}
};
byte keypadRowPins[keypadRows] = {8, 13, 12, 10}; //connect to the row pinouts of the keypad
byte keypadColPins[keypadCols] = {9, 7, 11}; //connect to the column pinouts of the keypad
Keypad keypad = Keypad( makeKeymap(keypadKeys), keypadRowPins, keypadColPins, keypadRows, keypadCols );

PCF8583* rtc;
static const char* month_names[12] = {
  "JAN ",
  "FEB ",
  "MAR ",
  "APR ",
  "MAY ",
  "JUNE",
  "JULY",
  "AUG ",
  "SEPT",
  "OCT ",
  "NOV ",
  "DEV "
};

void setup() {
  Serial.begin(115200);
  
  
//  Wire.begin();

  Serial.println("Time Circuit Clock - firmware Version " FIRMWARE_VERSION " initializing...");
  
  pinMode(BUTTON_FN1, INPUT);
  pinMode(BUTTON_FN2, INPUT);
  pinMode(BUTTON_FN3, INPUT);
  pinMode(BUTTON_FN4, INPUT);
  digitalWrite(BUTTON_FN1, LOW);
  digitalWrite(BUTTON_FN2, LOW);
  digitalWrite(BUTTON_FN3, LOW);
  digitalWrite(BUTTON_FN4, LOW);
  
  buttonFn1.attach(BUTTON_FN1);
  buttonFn1.interval(5);
  buttonFn2.attach(BUTTON_FN2);
  buttonFn2.interval(5);
  
  
  // power up radio
  delay(1000);
  radio.powerOn();
  // wait for other devices to initialize
  Serial.println("radio on!");
  delay(1000);
  
  radio.setVolume(radioVolume);
  radio.setChannel(radioChannel);
  
  rtc = new PCF8583(RTC_ADDRESS);
  /*
  rtc->second = 0;
  rtc->minute = 20;
  rtc->hour = 23;
  rtc->year = 2014;
  rtc->month = 4;
  rtc->day = 28;
  rtc->set_time();
  */
}

enum {
  I2C_DISPCMD_SET7  = 1,
  I2C_DISPCMD_SET14 = 2,
  I2C_DISPCMD_RESETA = 3,
  I2C_DISPCMD_BLINK7 = 4,
  I2C_DISPCMD_BLINK14 = 5
};



int loopCounter = 0;
enum {
  MODE_IDLE,
  MODE_RADIO_SEEK,
  MODE_RADIO_SET,
  MODE_SET_CLOCK,
  MODE_CONFIRM_SET_CLOCK
};
int mode = MODE_IDLE;
int inputFreq = 0;



int setClockPart = 0;
byte setClockValues[12];
#define SETCLOCK_MONTH1  0
#define SETCLOCK_MONTH2  1
#define SETCLOCK_DAY1   2
#define SETCLOCK_DAY2   3
#define SETCLOCK_YEAR1  4
#define SETCLOCK_YEAR2  5
#define SETCLOCK_YEAR3  6
#define SETCLOCK_YEAR4  7
#define SETCLOCK_HOUR1  8
#define SETCLOCK_HOUR2  9
#define SETCLOCK_MINUTE1 10
#define SETCLOCK_MINUTE2 11


void updateDisplays() {
  char buffer[30];
  char message[20];
  int channel;
  int day, year, hour, minute, month;
  char month_name[5];

  rtc->get_time();  
  // 7-segments
  
  if (mode == MODE_RADIO_SET) {
    channel = inputFreq;
  } else {
    channel = radioChannel;
  }

  Wire.beginTransmission(DISPLAY_ADDRESS);
  Wire.write(I2C_DISPCMD_RESETA);
  Wire.endTransmission();      
      
  if (mode == MODE_SET_CLOCK || mode == MODE_CONFIRM_SET_CLOCK) {
    month = setClockValues[SETCLOCK_MONTH1] * 10 + setClockValues[SETCLOCK_MONTH2];
    year = setClockValues[SETCLOCK_YEAR1] * 1000
        + setClockValues[SETCLOCK_YEAR2] * 100
        + setClockValues[SETCLOCK_YEAR3] * 10
        + setClockValues[SETCLOCK_YEAR4];
    day = setClockValues[SETCLOCK_DAY1] * 10 + setClockValues[SETCLOCK_DAY2];
    hour = setClockValues[SETCLOCK_HOUR1] * 10 + setClockValues[SETCLOCK_HOUR2];
    minute = setClockValues[SETCLOCK_MINUTE1] * 10 + setClockValues[SETCLOCK_MINUTE2];
    
    //year = 2000; month = 1; minute = 20; day = 13; hour = 16;
    if (setClockPart >= 2) {
      strcpy(month_name, month_names[month - 1]);
      /*Wire.beginTransmission(DISPLAY_ADDRESS);
      Wire.write(I2C_DISPCMD_BLINK7);
      Wire.write(10 + setClockPart - 2); 
      Wire.write(1);
      Wire.endTransmission();      */
    } else {
      sprintf(month_name, " %02d ", month);
      /*Wire.beginTransmission(DISPLAY_ADDRESS);
      Wire.write(I2C_DISPCMD_BLINK14);
      Wire.write(5 + setClockPart); 
      Wire.write(1);
      Wire.endTransmission();      */
    }
  } else {
    month = rtc->month;
    day = rtc->day;
    year = rtc->year;
    hour = rtc->hour;
    minute = rtc->minute;
    strcpy(month_name, month_names[month - 1]);
  }
    
  
  sprintf(buffer, "0519550600%02d%4d%02d%02d%4d", day, year, hour, minute, channel);
  Serial.print("7seg [");Serial.print(buffer); Serial.println("]");
  Wire.beginTransmission(DISPLAY_ADDRESS);
  Wire.write(I2C_DISPCMD_SET7);
  Wire.write(24);
  Wire.write((const uint8_t*)buffer, 24);
  Wire.endTransmission();
  // 14-segments
  if (mode == MODE_IDLE) {
    sprintf(message, "RADIO FM");
  } else if (mode == MODE_RADIO_SEEK) {
    sprintf(message, "SEEK STATION");
  } else if (mode == MODE_RADIO_SET) {
    sprintf(message, "SET FM FREQ");
  } else if (mode == MODE_SET_CLOCK) {
    sprintf(message, "SET CLOCK");
  } else if (mode == MODE_CONFIRM_SET_CLOCK) {
    sprintf(message, "SAVE CLOCK?");
  } else {
    sprintf(message, "WTF IS THIS");
  }
  sprintf(buffer, "NOV %s%s", month_name, message);
  Serial.print("14seg [");Serial.print(buffer); Serial.println("]");
  Wire.beginTransmission(DISPLAY_ADDRESS);
  int len = strlen(buffer);
  Wire.write(I2C_DISPCMD_SET14);
  Wire.write(len);
  Wire.write((const uint8_t*)buffer, len);
  Wire.endTransmission();    
 
}

void setupClockSet() {
  char buffer[15];
  setClockPart = 0;
  rtc->get_time();
  
  sprintf(buffer, "%02d%02d%04d%02d%02d", rtc->month, rtc->day, rtc->year, rtc->hour, rtc->minute);
  Serial.println(buffer);
  setClockValues[SETCLOCK_MONTH1] = buffer[SETCLOCK_MONTH1] - '0';
  setClockValues[SETCLOCK_MONTH2] = buffer[SETCLOCK_MONTH2] - '0';
  setClockValues[SETCLOCK_DAY1] = buffer[SETCLOCK_DAY1] - '0';
  setClockValues[SETCLOCK_DAY2] = buffer[SETCLOCK_DAY2] - '0';
  setClockValues[SETCLOCK_YEAR1] = buffer[SETCLOCK_YEAR1] - '0';
  setClockValues[SETCLOCK_YEAR2] = buffer[SETCLOCK_YEAR2] - '0';
  setClockValues[SETCLOCK_YEAR3] = buffer[SETCLOCK_YEAR3] - '0';
  setClockValues[SETCLOCK_YEAR4] = buffer[SETCLOCK_YEAR4] - '0';
  setClockValues[SETCLOCK_HOUR1] = buffer[SETCLOCK_HOUR1] - '0';
  setClockValues[SETCLOCK_HOUR2] = buffer[SETCLOCK_HOUR2] - '0';
  setClockValues[SETCLOCK_MINUTE1] = buffer[SETCLOCK_MINUTE1] - '0';
  setClockValues[SETCLOCK_MINUTE2] = buffer[SETCLOCK_MINUTE2] - '0';
  mode = MODE_SET_CLOCK;
  Serial.println("started setting new clock");
}
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

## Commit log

2014-04-13 updates to the board
    [year-led-r1.brd, year-shift-r1.brd, year-shift-r1.sch]
2014-04-14 Additional boards
    [day-led-r1.brd, day-led-r1.sch, time-led-r1.brd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]
2014-04-15 Date display and driver - sorry for the driver board layout, I'll fix if I decide to use it
    [date-led-r1.brd, date-led-r1.sch, date-shift-r1.brd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]
2014-04-17 Updated circuit and testing code
    [date-shift-r1.brd, date-shift-r1.sch]
2014-04-19 More schematics
    [month-led-r1.brd, month-led-r1.sch, time-led-r1.brd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]
2014-04-21 More updates
    [date-led-r1.brd, date-shift-r1.brd, date-shift-r1.sch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]
2014-04-23 Some progress
    [big-module-test1.brd, big-module-test1.sch, date2-shift-r1.brd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]
2014-04-25 Lots of schematics updates and some initial code
    [big-module-shift.brd, big-module-shift.sch, display-controller.brd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]
2014-04-26 new boards and source code
    [big-module-test1.brd, big-module-test1.sch, led-shift-r1.brd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]
2014-04-27 Updates big and small
    [main.brd, main.sch, temperature-shift-r1.brd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]
2014-04-29 Big Update
    [main.sch]

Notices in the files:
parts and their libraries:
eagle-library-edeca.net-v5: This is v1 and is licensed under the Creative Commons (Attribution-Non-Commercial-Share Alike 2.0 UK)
